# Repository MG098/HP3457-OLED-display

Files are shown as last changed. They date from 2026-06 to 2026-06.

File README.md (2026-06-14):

# HP3457-OLED-display
A modern replacement for the low contrast HP3457 Multimeter LCD

This is a remake of the original project made by Xyphro, remade in KiCad and with a simpler PCB.
It drops the complicated power supply structure and isolation, in favor of using internal charge pumps for OLED and a simple buffer chip.
The power is supplied directly through the ribbon cable.
Since the internal ribbon cable follows a DIP-16 dimensions, I decided to use a common DIP socket with pins bent flat to act as a SMD footprint.
This allows for a much simpler and smaller PCB, without the need to split it into two pieces, saving on cost and assembly.
I've also repladced the more uncommon ATMega8L with a very common ATMega328p.
The board is still fully compatibile with ATMega8L, however there are come changes in the code that needed to be made.
Below are the pictures for this simplified board:

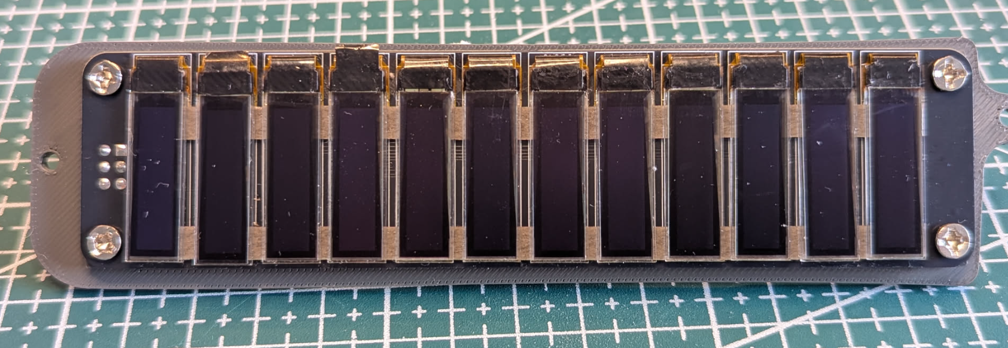
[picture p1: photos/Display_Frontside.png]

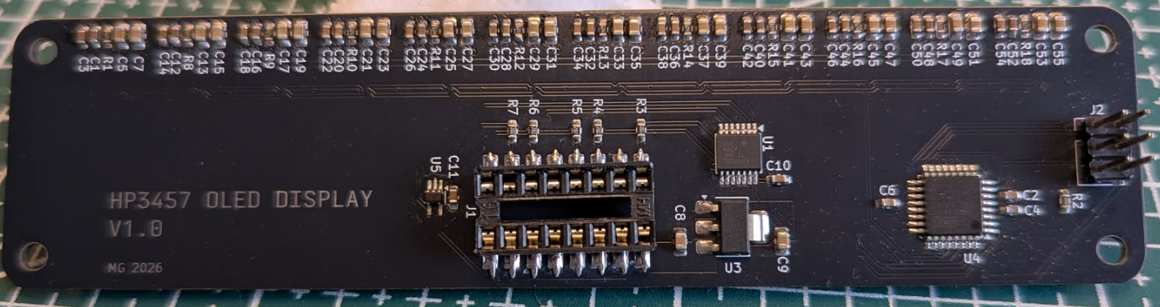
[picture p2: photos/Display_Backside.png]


# The final result:

I've added a bit of acryllic glass to hide the space between the digits.

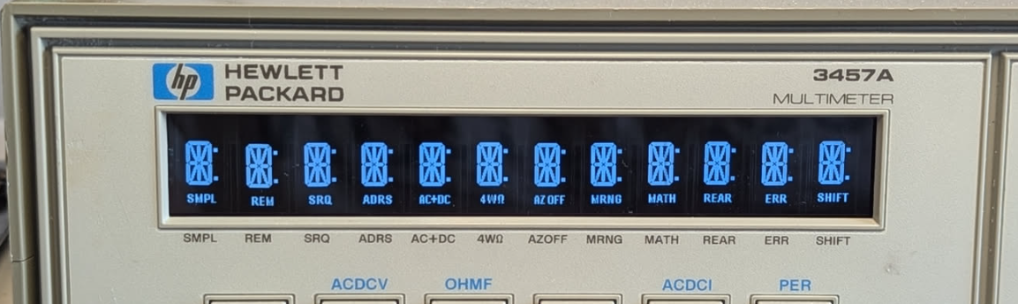
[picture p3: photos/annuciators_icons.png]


# Building the display yourself:

The build procedure is pretty much the same as the original project, but without splitting the board into two pieces.
It uses the same displays as the original project (SSD1316), and I haven't tested it with CH1115 displays.
The original Eagle files are left unchanged and server as a great inspiration.
My modified board is in KiCad folder, and I've also replaced the Gerber files.
If you decide to build this version, make sure that you use an ATMega that was programmed to use an internal oscillator.
I used one that I desoldered from an old arduino, and I couldn't program it before connecting external crystal.
Other fusebits should be set to 8MHz internal oscillator, with no divider.

# Putting it together

Since the display is now a single board, it's thinner than the original and won't fit easily into the multimeter.
For that, I've designed a simple bracket that enables the use of the original mounting holes.
I've included it the 3D folder, along with the 3D model for the board itself.
This bracked is 3D printed and uses brass threaded inserts and M3 screws.
It uses the original mounting holes and screws for the display itself.
After installing, the ribbon cable should fit nicely into the DIP socket and make electrical connection just fine.
The display is using the same 5V provided by the multimeter through the ribbon cable, so there is no need to hook it into AC supply section.
However, 5V into the display is connected through 1K resistor that would need to shorted, otherwise the voltage drop becomes too large.
Shown below is the resistor in question (R615), located right next to the ribbon cable connector.

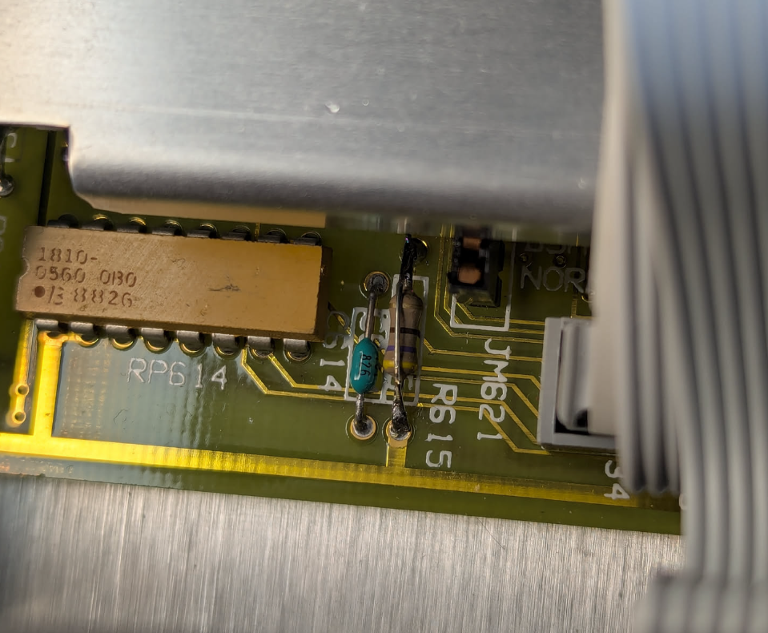
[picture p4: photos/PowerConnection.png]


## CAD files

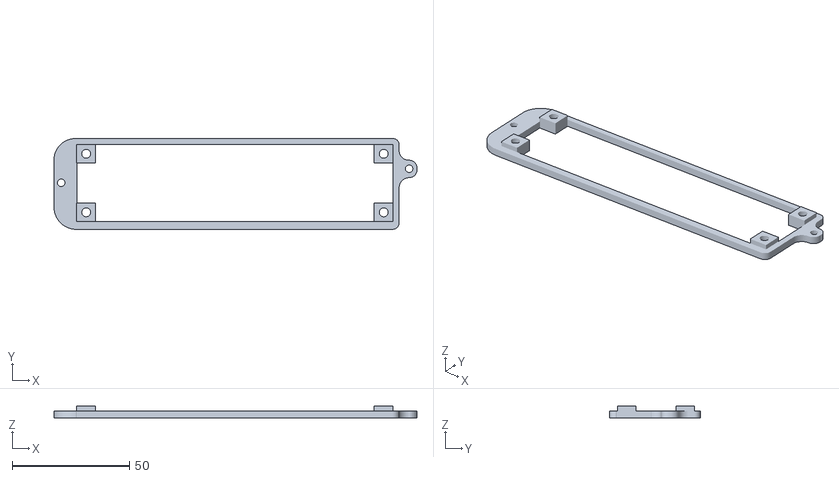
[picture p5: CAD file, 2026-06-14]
hardware/3D/Display_frame.stl
154.9 x 38.7 x 5.00

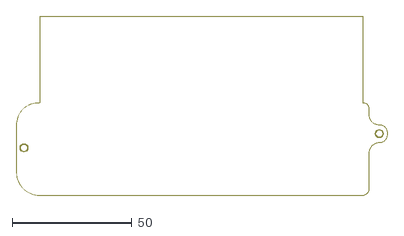
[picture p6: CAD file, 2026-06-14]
hardware/eagle/hp3547DisplayV2.dxf
155.1 x 75.0

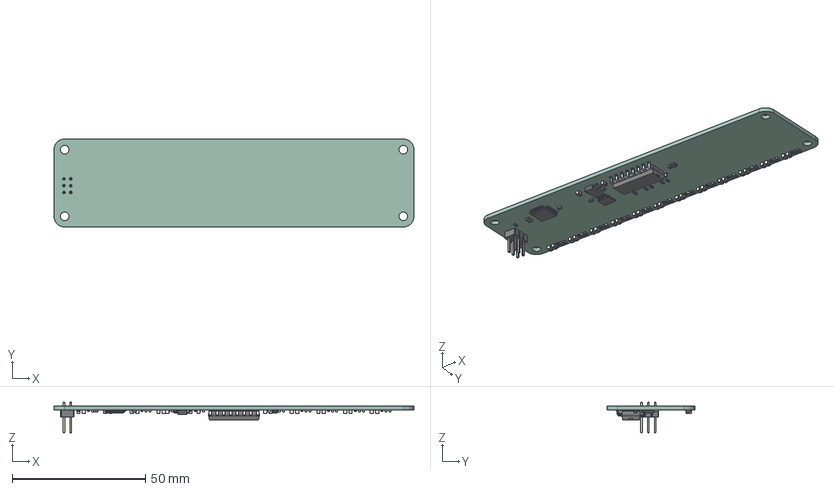
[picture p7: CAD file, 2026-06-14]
hardware/3D/hp3547Display.step
135.0 x 33.0 x 11.5 mm
C_0805_2012Metric x 26
C_0603_1608Metric x 29
R_0603_1608Metric x 18
SOT-223
PinHeader_2x03_P2.54mm_Vertical
TQFP-32_7x7mm_P0.8mm
TSSOP-14_4.4x5mm_P0.65mm
SMDIP-16_W11.48mm
SOT-353_SC-70-5
hp3547Display_PCB

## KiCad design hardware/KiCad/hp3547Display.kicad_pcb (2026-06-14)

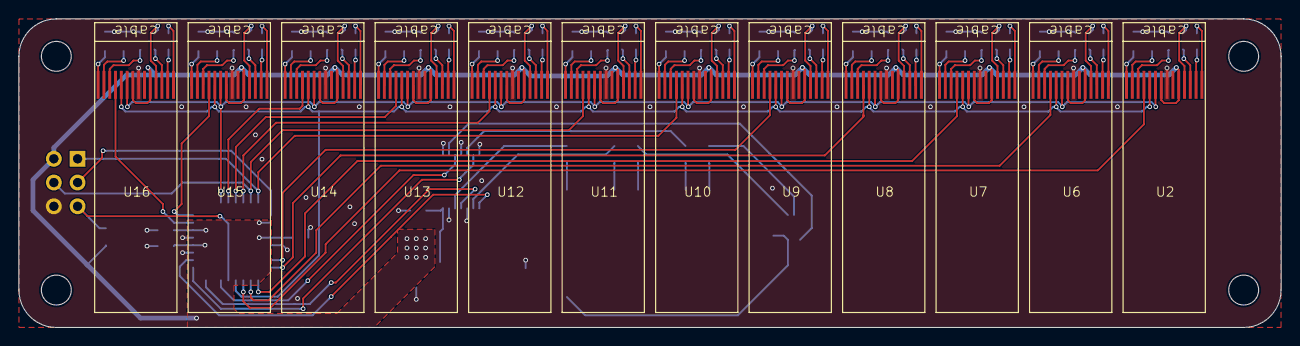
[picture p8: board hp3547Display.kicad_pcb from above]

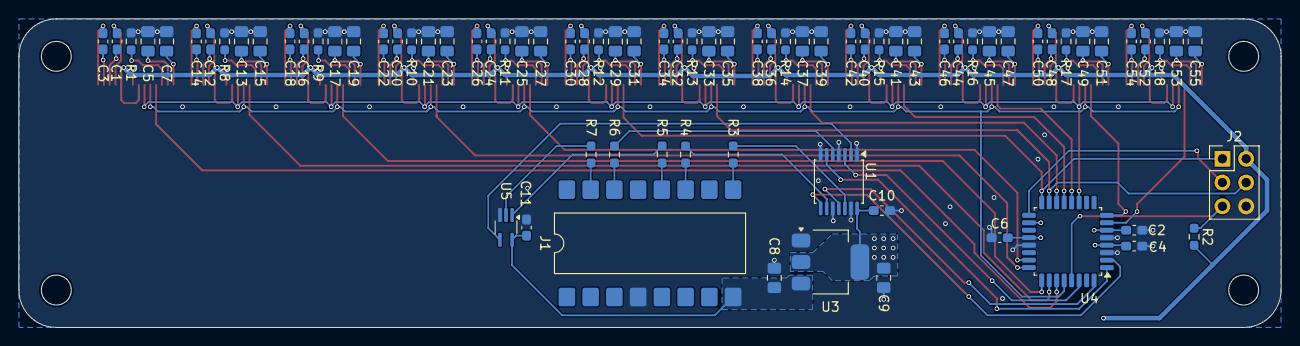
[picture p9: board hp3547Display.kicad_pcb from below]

Board: 2 copper layers, 135.0 x 33.0 mm, 95 parts (79 on the bottom side), 118 nets.

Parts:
C1, C2, C3, C4, C6, C10, C11, C12, C14, C16, C18, C20, C22, C24, C26, C28, C30, C32, C34, C36, C38, C40, C42, C44, C46, C48, C50, C52, C54: 1u; C_0603_1608Metric_Pad1.08x0.95mm_HandSolder
C5, C7, C8, C9, C13, C15, C17, C19, C21, C23, C25, C27, C29, C31, C33, C35, C37, C39, C41, C43, C45, C47, C49, C51, C53, C55: 2.2u; C_0805_2012Metric_Pad1.18x1.45mm_HandSolder
H1, H2, H3, H4: M3; MountingHole_3.2mm_M3
J1: HP_DISPLAY_CONN; SMDIP-16_W11.48mm
J2: ICSP; PinHeader_2x03_P2.54mm_Vertical
R1, R8, R9, R10, R11, R12, R13, R14, R15, R16, R17, R18: 560k; R_0603_1608Metric_Pad0.98x0.95mm_HandSolder
R2, R3, R4, R5, R6, R7: 2k; R_0603_1608Metric_Pad0.98x0.95mm_HandSolder
U1: SN74LV4T125; TSSOP-14_4.4x5mm_P0.65mm
U2, U6, U7, U8, U9, U10, U11, U12, U13, U14, U15, U16: OLED_14p; OLED_0.86_14p
U3: AMS1117-3.3; SOT-223-3_TabPin2
U4: ATmega8L-8A; TQFP-32_7x7mm_P0.8mm
U5: 74LVC1G86; SOT-353_SC-70-5_Handsoldering

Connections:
+3.3V: C2.1, C4.1, C6.1, C9.1, C10.1, J2.2, R2.2, U1.14 (VCC), U2.5 (VBAT), U2.8 (VDD), U3.2 (VO), U4.4 (VCC), U4.6 (VCC), U4.18 (AVCC), U4.20 (AREF), U6.5 (VBAT), U6.8 (VDD), U7.5 (VBAT), U7.8 (VDD), U8.5 (VBAT), U8.8 (VDD), U9.5 (VBAT), U9.8 (VDD), U10.5 (VBAT), U10.8 (VDD), U11.5 (VBAT), U11.8 (VDD), U12.5 (VBAT), U12.8 (VDD), U13.5 (VBAT), U13.8 (VDD), U14.5 (VBAT), U14.8 (VDD), U15.5 (VBAT), U15.8 (VDD), U16.5 (VBAT), U16.8 (VDD)
+5V: C8.1, C11.1, J1.8, U3.3 (VI), U5.5 (VCC)
/INA: R5.1, U5.1
/ISA: R7.1, U5.2
/O2: R4.1, U1.9
/PD0: U1.3, U4.30 (PD0)
/PD2: U1.11, U4.32 (PD2)
/PD3: U1.6, U4.1 (PD3)
/PD4: U1.8, U4.2 (PD4)
/PWO: R3.1, U1.12
/RES#: U2.9 (RES#), U4.11 (PD7), U6.9 (RES#), U7.9 (RES#), U8.9 (RES#), U9.9 (RES#), U10.9 (RES#), U11.9 (RES#), U12.9 (RES#), U13.9 (RES#), U14.9 (RES#), U15.9 (RES#), U16.9 (RES#)
/RST: J2.5, R2.1, U4.29 (PC6/~RESET)
/SCK: J2.3, U4.17 (PB5)
/SCL: U2.10 (SCL), U4.28 (PC5), U6.10 (SCL), U7.10 (SCL), U8.10 (SCL), U9.10 (SCL), U10.10 (SCL), U11.10 (SCL), U12.10 (SCL), U13.10 (SCL), U14.10 (SCL), U15.10 (SCL), U16.10 (SCL)
/SDA0: U2.11 (SDA), U4.27 (PC4)
/SDA1: U4.26 (PC3), U6.11 (SDA)
/SDA2: U4.25 (PC2), U7.11 (SDA)
/SDA3: U4.24 (PC1), U8.11 (SDA)
/SDA4: U4.23 (PC0), U9.11 (SDA)
/SDA5: J2.1, U4.16 (PB4), U10.11 (SDA)
/SDA6: J2.4, U4.15 (PB3), U11.11 (SDA)
/SDA7: U4.14 (PB2), U12.11 (SDA)
/SDA8: U4.13 (PB1), U13.11 (SDA)
/SDA9: U4.12 (PB0), U14.11 (SDA)
/SDA10: U4.8 (PB7/XTAL2), U15.11 (SDA)
/SDA11: U4.7 (PB6/XTAL1), U16.11 (SDA)
/SYNC: R6.1, U1.5
GND: C2.2, C4.2, C5.1, C6.2, C7.1, C8.2, C9.2, C10.2, C11.2, C13.1, C15.1, C17.1, C19.1, C21.1, C23.1, C25.1, C27.1, C29.1, C31.1, C33.1, C35.1, C37.1, C39.1, C41.1, C43.1, C45.1, C47.1, C49.1, C51.1, C53.1, C55.1, J1.4, J2.6, R1.2, R8.2, R9.2, R10.2, R11.2, R12.2, R13.2, R14.2, R15.2, R16.2, R17.2, R18.2, U1.1, U1.4, U1.7 (GND), U1.10, U1.13, U2.7 (VSS), U3.1 (GND), U4.3 (GND), U4.5 (GND), U4.21 (AGND), U5.3 (GND), U6.7 (VSS), U7.7 (VSS), U8.7 (VSS), U9.7 (VSS), U10.7 (VSS), U11.7 (VSS), U12.7 (VSS), U13.7 (VSS), U14.7 (VSS), U15.7 (VSS), U16.7 (VSS)
unnamed: J1.9, R3.2
unnamed: J1.11, R4.2
unnamed: J1.12, R5.2
unnamed: J1.14, R6.2
unnamed: J1.15, R7.2
unnamed: U1.2, U5.4
unnamed: C1.1, U2.4 (C1N)
unnamed: C1.2, U2.3 (C1P)
unnamed: C3.1, U2.2 (C2N)
unnamed: C3.2, U2.1 (C2P)
unnamed: R1.1, U2.12 (IREF)
unnamed: C7.2, U2.14 (VCC)
unnamed: C5.2, U2.13 (VCOMH)
unnamed: C12.1, U6.4 (C1N)
unnamed: C12.2, U6.3 (C1P)
unnamed: C14.1, U6.2 (C2N)
unnamed: C14.2, U6.1 (C2P)
unnamed: R8.1, U6.12 (IREF)
unnamed: C15.2, U6.14 (VCC)
unnamed: C13.2, U6.13 (VCOMH)
unnamed: C16.1, U7.4 (C1N)
unnamed: C16.2, U7.3 (C1P)
unnamed: C18.1, U7.2 (C2N)
unnamed: C18.2, U7.1 (C2P)
unnamed: R9.1, U7.12 (IREF)
unnamed: C19.2, U7.14 (VCC)
unnamed: C17.2, U7.13 (VCOMH)
unnamed: C20.1, U8.4 (C1N)
unnamed: C20.2, U8.3 (C1P)
unnamed: C22.1, U8.2 (C2N)
unnamed: C22.2, U8.1 (C2P)
unnamed: R10.1, U8.12 (IREF)
unnamed: C23.2, U8.14 (VCC)
unnamed: C21.2, U8.13 (VCOMH)
unnamed: C24.1, U9.4 (C1N)
unnamed: C24.2, U9.3 (C1P)
unnamed: C26.1, U9.2 (C2N)
unnamed: C26.2, U9.1 (C2P)
unnamed: R11.1, U9.12 (IREF)
unnamed: C27.2, U9.14 (VCC)
unnamed: C25.2, U9.13 (VCOMH)
unnamed: C28.1, U10.4 (C1N)
unnamed: C28.2, U10.3 (C1P)
unnamed: C30.1, U10.2 (C2N)
unnamed: C30.2, U10.1 (C2P)
unnamed: R12.1, U10.12 (IREF)
unnamed: C31.2, U10.14 (VCC)
unnamed: C29.2, U10.13 (VCOMH)
unnamed: C32.1, U11.4 (C1N)
unnamed: C32.2, U11.3 (C1P)
unnamed: C34.1, U11.2 (C2N)
unnamed: C34.2, U11.1 (C2P)
unnamed: R13.1, U11.12 (IREF)
unnamed: C35.2, U11.14 (VCC)
unnamed: C33.2, U11.13 (VCOMH)
unnamed: C36.1, U12.4 (C1N)
unnamed: C36.2, U12.3 (C1P)
unnamed: C38.1, U12.2 (C2N)
unnamed: C38.2, U12.1 (C2P)
unnamed: R14.1, U12.12 (IREF)
unnamed: C39.2, U12.14 (VCC)
unnamed: C37.2, U12.13 (VCOMH)
unnamed: C40.1, U13.4 (C1N)
unnamed: C40.2, U13.3 (C1P)
unnamed: C42.1, U13.2 (C2N)
unnamed: C42.2, U13.1 (C2P)
unnamed: R15.1, U13.12 (IREF)
unnamed: C43.2, U13.14 (VCC)
unnamed: C41.2, U13.13 (VCOMH)
unnamed: C44.1, U14.4 (C1N)
unnamed: C44.2, U14.3 (C1P)
unnamed: C46.1, U14.2 (C2N)
unnamed: C46.2, U14.1 (C2P)
unnamed: R16.1, U14.12 (IREF)
unnamed: C47.2, U14.14 (VCC)
unnamed: C45.2, U14.13 (VCOMH)
unnamed: C48.1, U15.4 (C1N)
unnamed: C48.2, U15.3 (C1P)
unnamed: C50.1, U15.2 (C2N)
unnamed: C50.2, U15.1 (C2P)
unnamed: R17.1, U15.12 (IREF)
unnamed: C51.2, U15.14 (VCC)
unnamed: C49.2, U15.13 (VCOMH)
unnamed: C52.1, U16.4 (C1N)
unnamed: C52.2, U16.3 (C1P)
unnamed: C54.1, U16.2 (C2N)
unnamed: C54.2, U16.1 (C2P)
unnamed: R18.1, U16.12 (IREF)
unnamed: C55.2, U16.14 (VCC)
unnamed: C53.2, U16.13 (VCOMH)

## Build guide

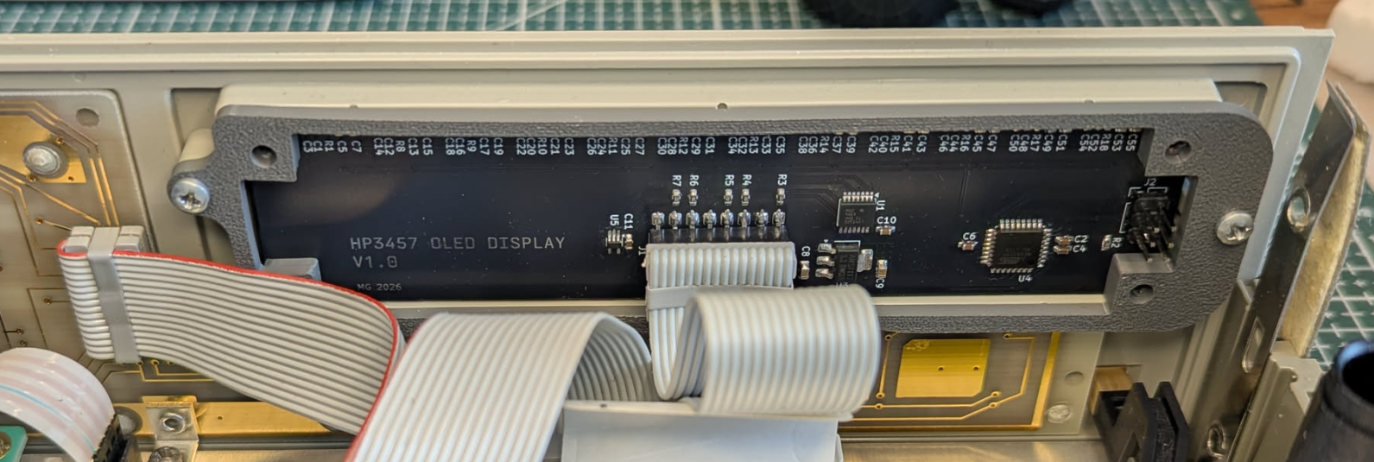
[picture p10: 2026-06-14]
photos/DisplayInstalled_backside.png

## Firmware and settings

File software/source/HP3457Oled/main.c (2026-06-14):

/*
 * HP3457Oled.c
 *
 * Created: 30.01.2022 18:13:05
 * Author : xyphro
 */ 

#include <avr/io.h>
#include "oled.h"
#include "pari2c.h"

#include <util/delay.h>
#include "hp_charset.h"
#include "hpdispprot.h"




int main(void)
{	
	oled_init();
	hpdp_init();
	
	DDRD &= ~(1<<3);
	DDRD |= (1<<5);
	
    while (1) 
    {
		uint8_t update = hpdp_update();
		if ( update & HPDP_UPDATE_DIGITS )
		{
			oled_repaint_digits(53);
		}
		if ( update & HPDP_UPDATE_ANNUCIATORS )
		{
			oled_repaint_annuciators(53-16);
		}
    }
}

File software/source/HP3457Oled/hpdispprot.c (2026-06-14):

#include <util/delay.h>
#include <avr/io.h>
#include <avr/interrupt.h>
#include <avr/pgmspace.h>
#include "hp_charset.h"
#include "hpdispprot.h"

#include "oled.h"



/***********************************************************************
 * Connection scheme:
 * PD0(RXD)    = INA ^ ISA (data) (Actually it would not be required to do a HW XOR, but here it helped to save 
 *                                 money for a 8 line isolator IC. In case you don't want galvanic isolation, you 
 *                                 could optimize the XOR IC away).
 * PD3(INT1)   = SYNC (high = command, low = data)
 * PD4(XCK/T0) = O2 (clock)
 * PD2(INT0)   = PWO (power up)
 **
 * Principle: 
 * The HP3457 sends datagrams that are command + data payload based.
 * The SYNC line identifies if the data is a command (SYNC = HIGH) or data (SYNC = LOW).
 * A command has a bitlength of 10 bits, the data payload is variable in length as function of the received command
 * 
 * PD3 is programmed to generate an interrupt on a rising edge (=start of a command).
 *   Once the interrupt arrives, To will be setup to generate an interrupt for every rising edge of the O2=clock line.
 * This timer interrupt does receive bits and store them for later processing.
 *
 * The actual display content will be flagged as valid so that it can be updated if no command is received within 10 ms
 *
 * Credits to Xi from EEvblog for decoding!
 ***********************************************************************/

// Timeout value based on 7k8125 Hz clock (78 cycles ~= 10ms)
// If no commands are received within this period, the display will be updated
#define TIMEOUT_VALUE (78)


// Below commands are known commands and most of them interpreted. Unknown commands are not handled and get simply ignored
#define	CMD_WRA12L  (0x0a) /* = 0x0A x4 = 0x028 = write registers A for the 12 digits */
#define	CMD_WRB12L  (0x1a) /* = 0x1A x4 = 0x068 = write registers B for the 12 digits */
#define CMD_WRC12L  (0x2a) /* = 0x2A x4 = 0x0A8 = write registers C for the 12 digits */
#define	CMD_WRAB6L  (0x3a) /* = 0x3A x4 = 0x0E8 = shift left 6 digits and write registers AB for the 6 digits */
#define	CMD_WRABC4L (0x4a) /* = 0x4A x4 = 0x128 = shift left 4 digits and write registers ABC for the 4 digits */
#define	CMD_WRAB6R  (0x5a) /* = 0x5A x4 = 0x168 = shift right 6 digits and write registers AB for the 6 digits */
#define	CMD_WRABC4R (0x6a) /* = 0x6A x4 = 0x1a8 = shift right 4 digits and write registers ABC for the 4 digits */
#define	CMD_WRA1L   (0x7a) /* = 0x7A x4 = 0x1e8 = shift left 1 digit and write registers A for 1 digit */
#define	CMD_WRB1L   (0x8a) /* = 0x8A x4 = 0x228 = shift left 1 digit and write registers B for 1 digit */
#define	CMD_WRC1L   (0x9a) /* = 0x9A x4 = 0x268 = shift left 1 digit and write registers C for 1 digit */
#define	CMD_WRA1R   (0xaa) /* = 0xAA x4 = 0x2a8 = shift right 1 digit and write registers A for 1 digit */
#define	CMD_WRB1R   (0xba) /* = 0xBA x4 = 0x2e8 = shift right 1 digit and write registers B for 1 digit */
#define	CMD_WRAB1L  (0xca) /* = 0xCA x4 = 0x328 = shift left 1 digit and write registers AB for 1 digit */
#define	CMD_WRAB1R  (0xda) /* = 0xDA x4 = 0x368 = shift right 1 digit and write registers AB for 1 digit */
#define	CMD_WRABC1L (0xea) /* = 0xEA x4 = 0x3a8 = shift left 1 digit and write registers ABC for 1 digit */
#define	CMD_WRABC1R (0xfa) /* = 0xFA x4 = 0x3e8 = shift left 1 digit and write registers ABC for 1 digit */
#define	CMD_WRITAN  (0xbc) /* = 0xBC x4 = 0x2F0 = write the annunciators (eg the little arrows that are below the digits). The annunciators will follow in the data frame ("INA" line): there is one bit per annunciator, and the top right annunciator is transmitted first */

#define	CMD_DISOFF       (0x8C) /* = 0x8C x4 = 0x230 = Turn display off */
#define	CMD_DISTOG       (0xC8) /* = 0xC8 x4 = 0x320 = toggle the display ON/OFF (I don't know why this command is sent everytime (the sequence is always FC, B8, C8, BC, ...), maybe the unknow command B8 tells to switch the display OFF, then the C8 command swithes the display ON?) */
#define	CMD_PERSCLT      (0xfc) /* = 0xFC x4 = 0x3F0 = select the display if the following data field contains 0xF 0xD (that's always the case for HP3457a) */

volatile uint8_t hpdp_dat = 0;
volatile uint8_t hpdp_expectedsz = 0;
volatile uint8_t hpdp_sz = 0;
volatile bool    hpdp_nextiscmd;
volatile bool	hpdp_cmdisknown;
volatile uint8_t hpdp_msg[12], hpdp_cmd;
volatile uint8_t hpdp_updateflag; // update with information which part of the display should be update

volatile uint8_t hdpd_reg_a[12];  // 4 bit registers from that display content will be assembled
volatile uint8_t hdpd_reg_b[12];  // the character code is (reg_c&1<<6) | (reg_b&3)<<4 | reg_a
volatile uint8_t hdpd_reg_c[12];  // the period is encoded in reg_b bit 2 and 3

volatile bool    hpdp_displayselected = true; // used to handle the PERSCLT command - the default value can be incorrect - could not confirm it yet
volatile bool    hpdp_displayon       = true;  // Stores the on/off state of the display - the default value on has to be right, because HP3852a does never send a command to turn the display on

uint8_t cnt=0; // bitcounter for display command receiver

// PD3 interrupt - triggered on every rising edge of the PD3 pin 
ISR(INT1_vect)
{
	if (PIND & (1<<2))
	{ // only decode when PWO signal is high
		TCNT0 = -3; // Skip first 2 bits after SYNC edge
		TCCR0B = (7<<CS00); // enable Timer 0 (precondition here is, that TCNT is -3)
		hpdp_nextiscmd = true;
		cnt = 0;
	}
}


uint8_t kommaxlate  [] = {0, 2, 6, 3}; // none, period, colon, comma
uint8_t datalenxlate[] = {12, 12, 12, 12, 12, 12, 12, 1, 1, 1, 1, 1, 2, 2, 3, 3}; // payload count of all write command

// below function will trigger a display update 10ms after it was called
static void hpdp_scheduledisplayupdate(void)
{
	hpdp_updateflag |= HPDP_UPDATE_DIGITS;
	hpdp_updateflag |= HPDP_UPDATE_ANNUCIATORS;
	
	// Timer 1 is set as generic up counting counter and used as timeout to flag,
	// that the display should be updated.
	TCNT1H = (0xffff-TIMEOUT_VALUE) >> 8; TCNT1L = (0xffff-TIMEOUT_VALUE) & 0xff; // reset timer
	TCCR1B = (5<<0); // 8 MHz / 1024 = 7k8125 Hz => 16 bit timer value wraps every 8.4s, 8 bit LSB wraps every 32m768s
}
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
